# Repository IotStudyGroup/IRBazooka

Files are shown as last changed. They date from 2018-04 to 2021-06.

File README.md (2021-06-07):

# IRBazooka

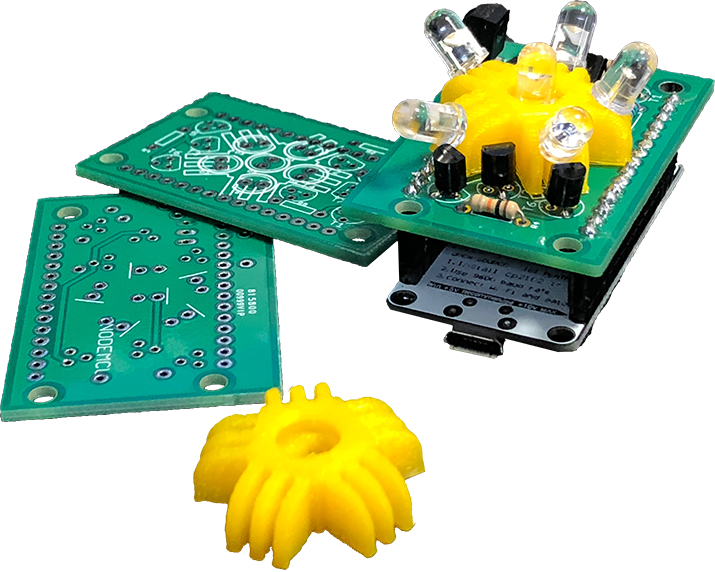
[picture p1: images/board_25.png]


This is the initial repository for our IoT Study Group.

The aim of this project is to create an automated way of turning off all the AC units in the office at some specified time, with the intention of reducing our energy consumption. Alexa integration is also on the roadmap, in order to control the AC units with only our voice power.

# Instructions

```bash
$ git clone --recursive https://github.com/IotStudyGroup/IRBazooka.git
```

## Folder structure

- Eagle
  - PCB files.
- Led-holder
  - 3D Printed files for the LED holder. You don't actually need it. But it makes it easier to position the LEDs.
- NodeMCU
  - Firmware (WORKING IN PROGRESS - NOT USABLE YET)
- OpenMQTTGateway (git submodule)
  - open firmware that works great!

# Bill Of Materials
These are the components necessary to build the board
```
Qty   Value            Description

 2    10kΩ             10kΩ resistor
 3    1kΩ              1kΩ resistor
 7    2N3904           NPN Transistror
 1    S8550            PNP Transistror
 1    ESP12E_DEVKIT    NodeMCU v2
 6    LED-IRTSAL6100   Infrared LED (IR)
 1    TSOP4838         IR Receiver and Demodulator
 ```
 Link for buying at Filipe Flop:<br>
 * [10kΩ resistor](https://www.filipeflop.com/produto/resistor-10k%CF%89-14w-x20-unidades/)<br>
 * [1kΩ resistor](https://www.filipeflop.com/produto/resistor-1k%CF%89-14w-x20-unidades/)<br>
 * [2N3904](https://www.filipeflop.com/produto/transistor-2n3904-npn-x10-unidades/)<br>
 * [S8550](https://www.filipeflop.com/produto/transistor-s8550-pnp-x10-unidades/)<br>
 * [ESP12E_DEVKIT](https://www.filipeflop.com/produto/modulo-wifi-esp8266-nodemcu-esp-12/)<br>
 * [LED-IRTSAL6100](https://www.filipeflop.com/produto/led-emissor-infravermelho-ir-5mm/)<br>
 * [TSOP4838](https://www.filipeflop.com/produto/receptor-infravermelho-ir-tsop4838/)<br>

# Pins:
- D1 (GPIO5) - IR Receiver
- D2 (GPIO4) - IR LEDs

# How to use it:
The easiest way is to use it with [ESPHome](https://esphome.io/index.html)
Here's an example of a configuration of a LG AC:
```yaml
substitutions:
  name: "Bedroom AC"

esphome:
  name: bedroom_ac
  platform: ESP8266
  board: nodemcuv2

wifi:
  ssid: !secret wifi_ssid
  password: !secret wifi_password

  # Enable fallback hotspot (captive portal) in case wifi connection fails
  ap:
    ssid: "Bedroom Ac Fallback Hotspot"
    password: !secret wifi_password

captive_portal:

# Enable logging
logger:

# Enable Home Assistant API
api:

ota:

remote_receiver:
  id: receiver
  pin:
    number: D1
    inverted: true
  dump: raw

remote_transmitter:
  pin: D2
  carrier_duty_percent: 50%

# Using a temperature sensor from Home Assistant
sensor:
  - platform: homeassistant
    name: "temp sensor"
    internal: true
    id: temp_sensor
    entity_id: sensor.bedroom_temperature

climate:
  name: "${name}"
  platform: climate_ir_lg
  receiver_id: receiver
  sensor: temp_sensor
  header_high: 3265us # AC Units from LG in Brazil, for example use these timings
  header_low: 9856us
```

# References
- Circuit inspired by [Harald Braun's IRBridge](https://www.hackster.io/har-bra/irbridge-controlling-ir-devices-via-alexa-web-interface-66ca06)

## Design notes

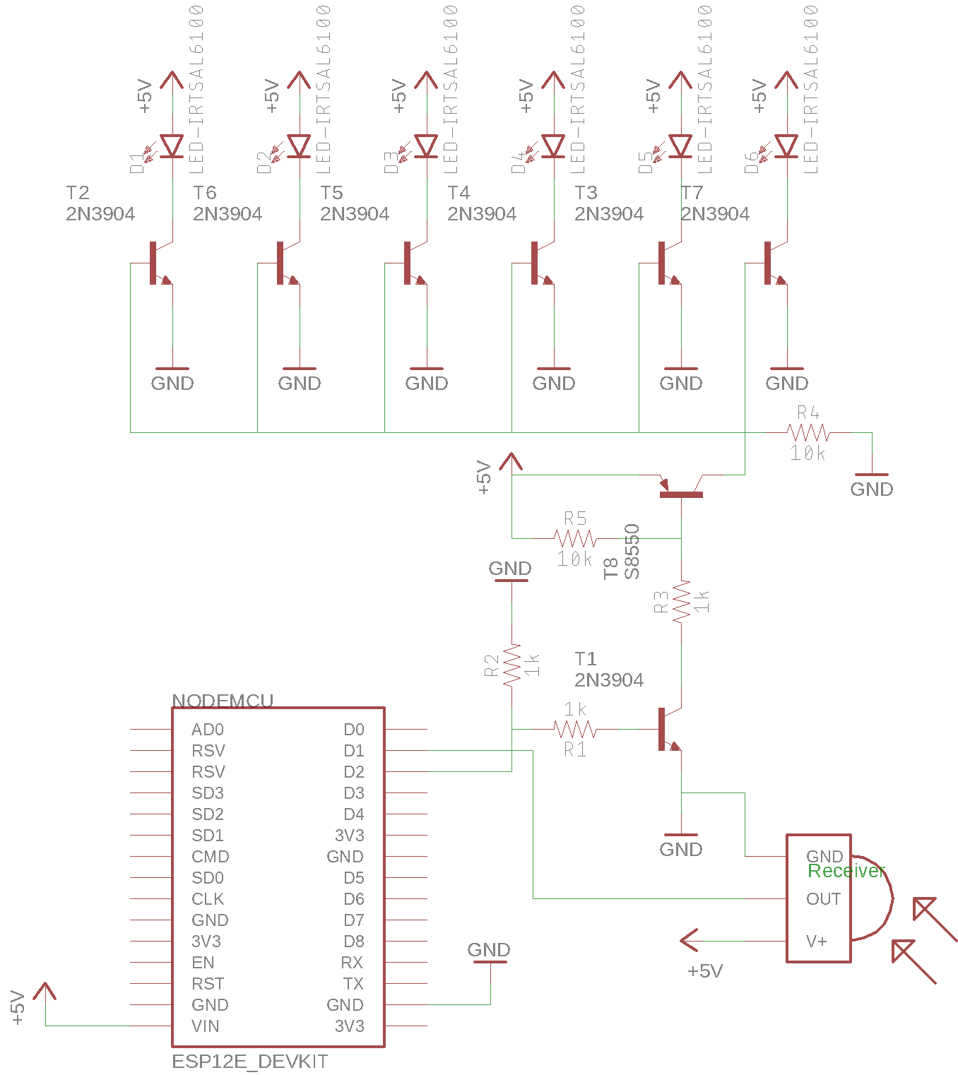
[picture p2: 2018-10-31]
images/schematic.png

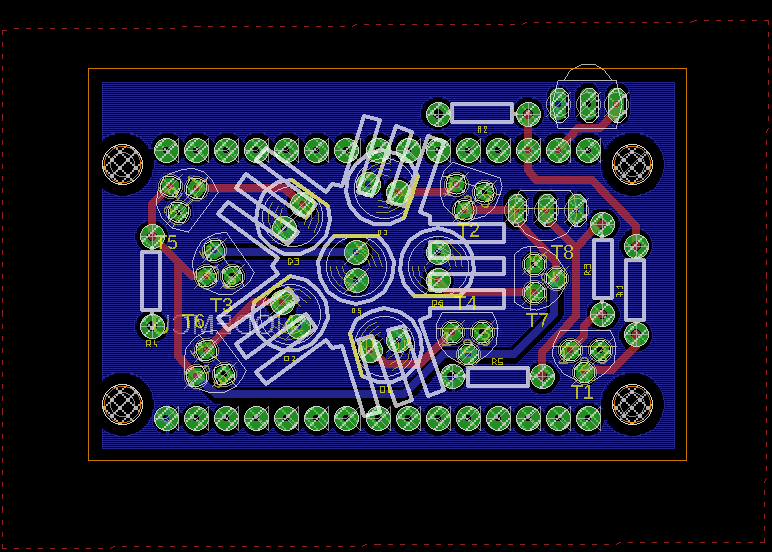
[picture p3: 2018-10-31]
images/pcb.png

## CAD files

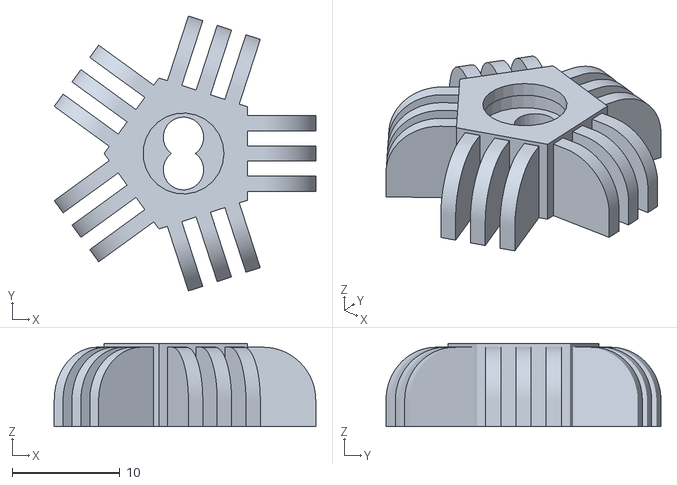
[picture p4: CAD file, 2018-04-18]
Led-holder/led-holder.stl
24.2 x 25.5 x 7.70

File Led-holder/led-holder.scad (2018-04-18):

led_scale = 1.5;
leds_in_circle = 5;


//LED Dimensions
led_d=5; //LED Diameter
led_h=8; //LED Height
led_fh=1; //LED FLange Thickness
led_fd=5.5; //LED Flange Diameter
wire_d=2.5;//0.5; //Wire Diameter
wire_h=10; //Wire Height
wire_da=2; // THe distance between the Wires
module led(){
	union() {
		translate([0,0,led_fh-1])cylinder(led_h-(led_d/2)-led_fh+1,led_d/2,led_d/2, $fn=25);
		translate([0,0,led_h-(led_d/2)])sphere(led_d/2,  $fn=25);
		cylinder(led_fh,led_fd/2,led_fd/2, $fn=25);
		translate([0,wire_da/2,-wire_h])cylinder(wire_h+1,wire_d/2,wire_d/2, $fn=25);
		translate([0,wire_da/-2,-wire_h])cylinder(wire_h+1,wire_d/2,wire_d/2, $fn=25);

	}
}

module scaled_led() {
	scale([led_scale,led_scale,led_scale]) {
		led();
	}
}

led_hole_size = 2;
support_r = 7; //radius

module all_leds() {
	difference() {
		scale(0.7) union() {
			rotate([0,0,180/leds_in_circle]) cylinder(r=support_r*1.5, h=11,$fn=leds_in_circle);
			translate([0,0,support_r/2]) for(x=[0:1:leds_in_circle]) {
				angle = x * (360/leds_in_circle);
				rotate([0,0,angle]) {
					// rotate([0,45,0]){
					translate([support_r*1.5,0,0]) led_legs();
						// }
				}
			}
		}
		translate([0,0,5]) scaled_led();
	}
}



module led_leg() {
	rotate([90,90,0]) linear_extrude(wire_da, center=true) {
		difference() {
			union() {
				circle(support_r, $fn=100);		
				translate([-support_r,-support_r,0]) square([support_r*2,support_r], center=false);
				translate([0,-support_r,0]) square([support_r,support_r*2], center=false);
			}
			translate([support_r/2,-support_r,0]) square([support_r,support_r*2], center=false);
			translate([-support_r,-support_r,0]) square([support_r*2,support_r/2], center=false);
		}
	}
}

module led_legs() {
	y_distance = wire_da+led_hole_size;
	for(i=[-1:1:1]) {
		translate([0,i*y_distance,0]) {
			led_leg();
		}
	}
}

cube_size = ((support_r*2)+led_d)*2;
// projection()
all_leds();

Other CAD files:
Led-holder/led-holder.dxf

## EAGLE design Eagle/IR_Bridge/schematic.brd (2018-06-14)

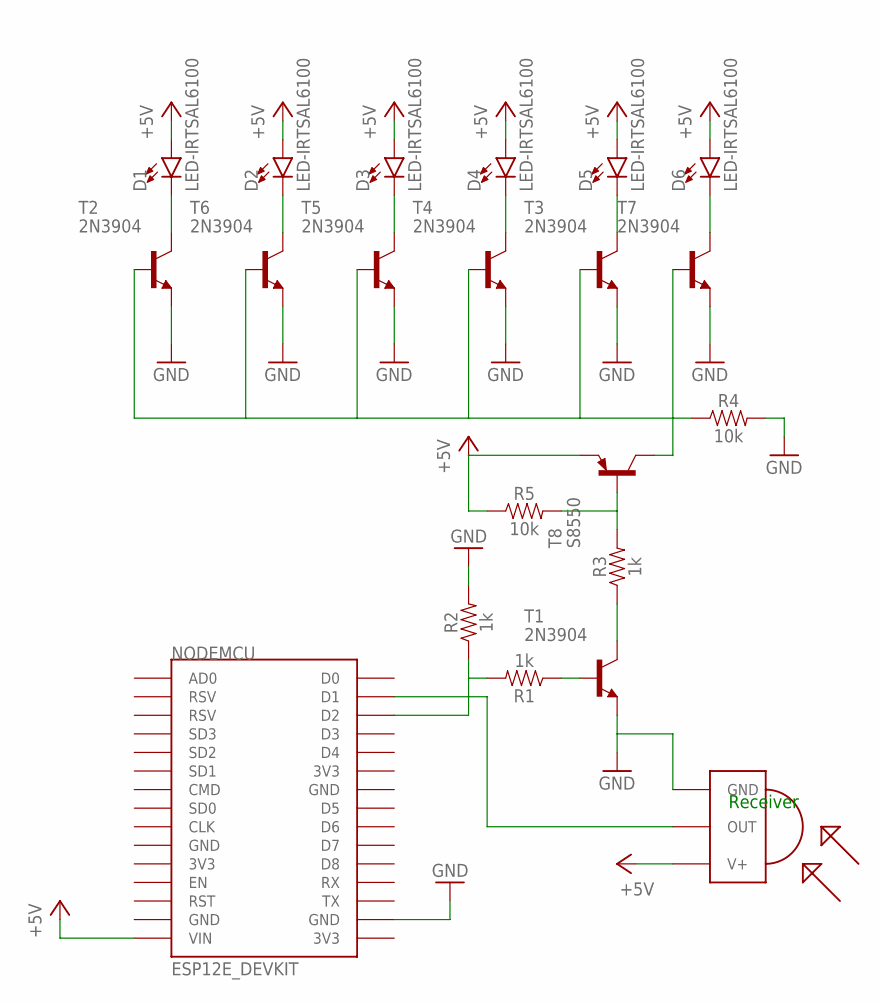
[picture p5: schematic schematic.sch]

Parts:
D1, D2, D3, D4, D5, D6: LED-IRTSAL6100; LED_5MM
NODEMCU: ESP12E_DEVKIT
R1, R2, R3: 1k; AXIAL-0.3; MPN MCF 0.25W 1K
R4, R5: 10k; AXIAL-0.3; MPN MCF 0.25W 10K
RECEIVER: TSOP4838; TSOP18XX; MPN TSOP4838
T1, T2, T3, T4, T5, T6, T7: 2N3904; TO92; MPN 2N3904BU
T8: S8550; TO92-EBC

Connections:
+5V: D1.A, D2.A, D3.A, D4.A, D5.A, D6.A, NODEMCU.VIN, R5.P$1 (1), RECEIVER.VCC (V+), T8.E
GND: NODEMCU.GND@3 (GND), R2.P$2 (2), R4.P$2 (2), RECEIVER.GND, T1.3 (E), T2.3 (E), T3.3 (E), T4.3 (E), T5.3 (E), T6.3 (E), T7.3 (E)
unnamed: NODEMCU.D2, R1.P$2 (2), R2.P$1 (1)
unnamed: R4.P$1 (1), T2.2 (B), T3.2 (B), T4.2 (B), T5.2 (B), T6.2 (B), T7.2 (B), T8.C
unnamed: R1.P$1 (1), T1.2 (B)
unnamed: R3.P$1 (1), T1.1 (C)
unnamed: R3.P$2 (2), R5.P$2 (2), T8.B
unnamed: NODEMCU.D1, RECEIVER.OUT
unnamed: D6.K (C), T7.1 (C)
unnamed: D1.K (C), T2.1 (C)
unnamed: D2.K (C), T6.1 (C)
unnamed: D3.K (C), T5.1 (C)
unnamed: D4.K (C), T4.1 (C)
unnamed: D5.K (C), T3.1 (C)

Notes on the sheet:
Receiver

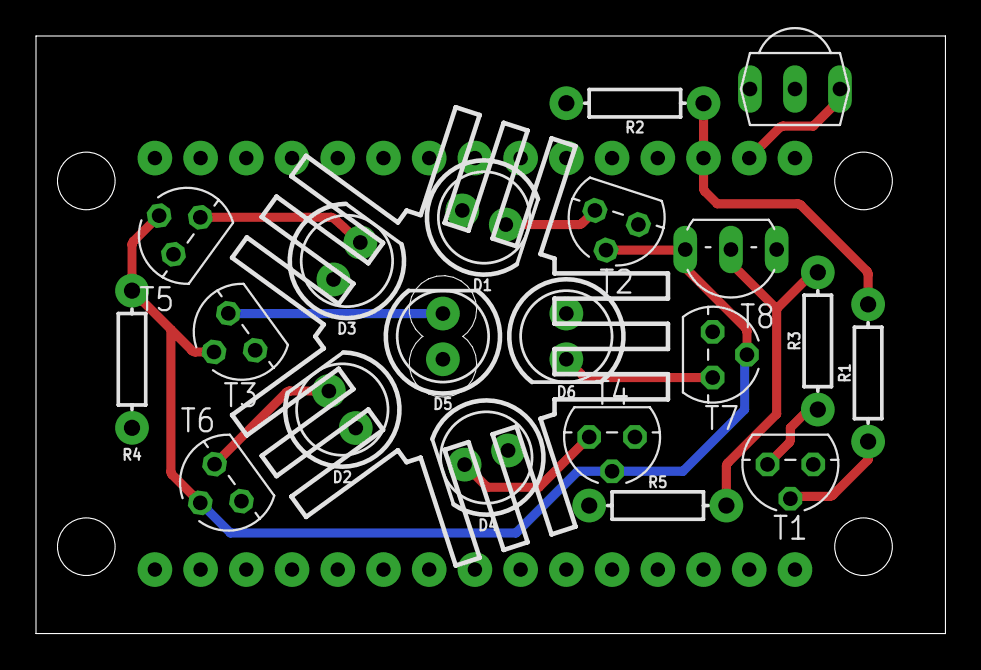
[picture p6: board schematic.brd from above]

Board: 2 copper layers, 50.5 x 33.2 mm, 21 parts (1 on the bottom side), 14 nets.

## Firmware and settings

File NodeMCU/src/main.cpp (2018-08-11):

#include <Arduino.h>

#include <ESP8266WiFi.h>
#include <PubSubClient.h>
#include <ESP8266mDNS.h>
#include <WiFiUdp.h>
#include <ArduinoOTA.h>
#include <IRsend.h>
#include <string.h>

#define SSID ""
#define PASS ""

#define MQTT_SERVER ""
#define MQTT_PORT 1883
#define MQTT_USER ""
#define MQTT_PASS ""

#define OTA_PASS "UPDATE_PW"
#define OTA_PORT 8266

// #define LED_PIN D0

#define IR_PIN D2

#define ESP_NAME "IRBAZOOKA"

const char* irTopic = "ckl/funroom/projector";

WiFiClient espClient;
PubSubClient client(espClient);

IRsend irsend(IR_PIN);
const uint64_t PROJECTOR_POWER = 0xC1AA09F6;

uint64_t lastMQTTCheck = -10000;

void initWifi() {
    Serial.println();
    Serial.print("Connecting to ");
    Serial.println(SSID);

    WiFi.begin(SSID, PASS);
}

void checkMQTTConnection() {
    Serial.print("Checking MQTT connection: ");
    if (client.connected()) {
        Serial.println("OK");
    } else {
        if (WiFi.status() == WL_CONNECTED) {
            Serial.print("new connection: ");
            if (client.connect(ESP_NAME, MQTT_USER, MQTT_PASS)) {
                Serial.println("connected");
                client.subscribe(irTopic);
            } else {
                Serial.print("failed, rc=");
                Serial.println(client.state());
            }
        } else {
            Serial.println(" Not connected to WiFI AP, abandoned connect.");
        }
    }
    if (client.connected()) {
        // digitalWrite(LED_PIN, HIGH);
    } else {
        // digitalWrite(LED_PIN, LOW);
    }
}

void MQTTcallback(char* payloadTopic, byte* payload, unsigned int length) {
    Serial.print("Message arrived [");
    Serial.print(irTopic);
    Serial.println("] ");

    if (strcmp(payloadTopic, irTopic) == 0) {
      Serial.println("SENDING COMMAND");
        irsend.sendNEC(PROJECTOR_POWER, 32);
    }
}

void setup() {
    pinMode(IR_PIN, OUTPUT);
    digitalWrite(IR_PIN, LOW);
    irsend.begin();
    Serial.begin(115200, SERIAL_8N1, SERIAL_TX_ONLY);

    initWifi();

    client.setServer(MQTT_SERVER, MQTT_PORT);
    client.setCallback(MQTTcallback);

    ArduinoOTA.setPort(OTA_PORT);
    ArduinoOTA.setHostname(ESP_NAME);
    ArduinoOTA.setPassword(OTA_PASS);
    ArduinoOTA.begin();
}

void loop() {
    if (millis() - lastMQTTCheck >= 10000) {
        checkMQTTConnection();
        lastMQTTCheck = millis();
    }

    // Handle any pending MQTT messages
    client.loop();

    // Handle any pending OTA SW updates
    ArduinoOTA.handle();
}

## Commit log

2018-04-18 Add board files
    [schematic.brd, schematic.sch]
2018-04-18 Add led holder files
    [led-holder.dxf, led-holder.scad, led-holder.stl]
2018-04-25 Finish designing PCB
    [schematic.brd, schematic.sch]
2018-04-25 Remove values from silk
    [schematic.brd]
2018-04-25 Fix some issues on the PCB
    [schematic.brd]
2018-04-25 Move some labels around
    [schematic.brd]
2018-04-25 Prepare board to fabricate
2018-06-18 Add board image
2018-06-21 Add bill of materials
2018-10-30 Add schematic and pcb images

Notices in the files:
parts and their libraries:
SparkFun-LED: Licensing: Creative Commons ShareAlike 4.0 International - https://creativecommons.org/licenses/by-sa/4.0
